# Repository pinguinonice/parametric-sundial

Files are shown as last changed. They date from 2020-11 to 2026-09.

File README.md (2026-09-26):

# parametric-sundial

A web generator for a 3D-printable **Bernhardt precision sundial** (equatorial ring dial with
a *Bernhardtsche Walze*, the shaped roller gnomon that builds the equation of time into the
shadow so the dial reads mean zone time to the minute). Enter a location, get four STL files:
the organic crescent dial, the two rollers (one per half year) and a stand tilted to your latitude.

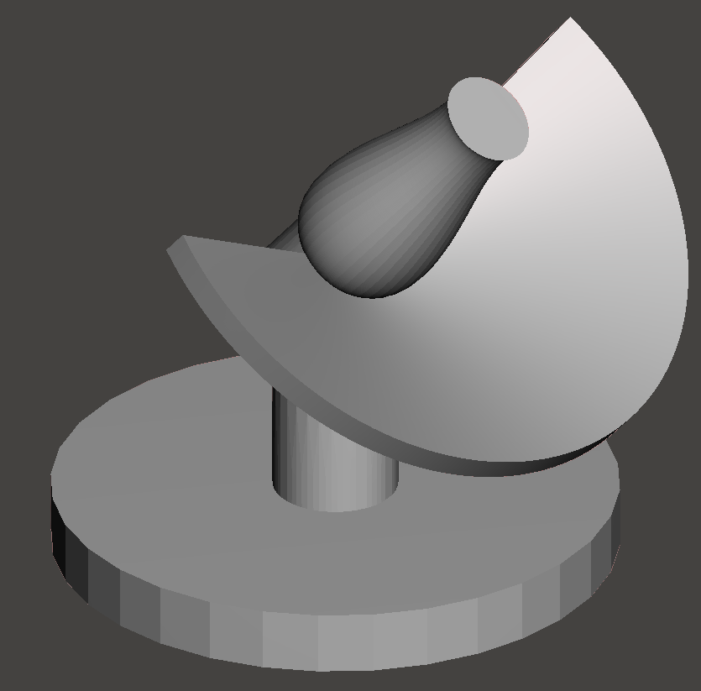
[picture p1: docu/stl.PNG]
original dial


## Run it

```bash
pip install -r app/requirements.txt
cd app && uvicorn sundialweb.api:app --reload
# open http://127.0.0.1:8000
```

or with Docker:

```bash
docker build -t sundial . && docker run -p 8000:8000 sundial
```

Command line, no server:

```bash
cd app && python -m sundialweb.cli --lat 48.7758 --lon 9.1829 --utc 1 --label "CET  UTC+1" -o out/
```

## Host it for free

The app is a single container (Dockerfile in the repo, honours `PORT`) and needs about 300 MB
of RAM and a few seconds of CPU per generation, so the free tiers are enough:

* **Hugging Face Spaces** (simplest, no card): create a Space with the *Docker* SDK, push this
  repo to it, and add `app_port: 8000` to the Space's README front matter. Spaces sleep after
  48 h without visitors and wake on the next request.
* **Render**: fork the repo, then *New > Blueprint* and pick `render.yaml`. The free web service
  sleeps after 15 min idle and takes about a minute to wake.
* **Google Cloud Run**: `gcloud run deploy --source .` from the repo root; scales to zero and the
  monthly free tier covers hobby traffic.

Generated results are cached in `SUNDIAL_CACHE` (default: the system temp dir); on these hosts
the cache is wiped on restart, which is fine.

## What the site does

The page is a four-beat flow, mobile first:

1. **Where am I.** The opening shows the last dial anyone made, with the sun looping through
   its day, beside a place card: use my location, search a town (or type coordinates), adjust
   on a map. The card shows the tilt, the engraved hour range and whether the zone keeps summer
   time before anything is built. One button: *Make my sundial*.
2. **Making it.** The facts of the dial appear at once (longest day, hours, roller waist, tilt),
   the analemma draws itself, and six named stages tick off as the server builds (design, dial,
   roller I, roller II, base, packing) with an estimate from the last builds. A repeat request
   comes from the cache. A closed tab can be reopened within ten minutes and picks the job up.
3. **Your dial today.** The viewer opens at the place's current standard time with the right
   roller fitted, or, when the sun is down or outside the engraved hours, at tomorrow's first
   light on the dial. The page's own shadows follow the sun of the moment shown.
4. **Take it home.** One ZIP button (size and bed hint), a *Buy us a coffee* button beside it
   that explains the server cost and never gates anything, part previews on a build plate with
   size, volume, weight and support hints, print notes, setup steps and a share link.

Settings (diameter, year, hour range, roller neck, labels, manual coordinates) and the full
numbers live one tap away in side sheets. A quiet *Dial map* in the top bar shows where dials
have been made (one entry per session per minute, coordinates to a tenth of a degree). Seven
languages, right-to-left included; the stories behind the design are in `docs/web-stories.md`.

### API

| Route | What it does |
|---|---|
| `GET /api/timezone?lat&lon` | standard offset, zone name, summer-time label |
| `GET /api/design?lat&lon&utc_offset_h&year&scale_radius…` | the dial's facts without meshing (a few seconds, cached) |
| `POST /api/generate` | `{cached: true, info}` at once, or `{job, estimates, stages}`; header `X-Sundial-Session` for the map |
| `GET /api/jobs/{id}` and `/events` | job status; server-sent events with the current stage |
| `GET /api/files/{key}/{name}` | `dial.stl`, `roller_1.stl`, `roller_2.stl`, `stand.stl`, `sundial.zip`, `viewer.glb` (decimated, for the browser) |
| `GET /api/latest` | the last dial made, for the opening picture |
| `GET /api/history` | where dials have been made, for the map |
| `GET /api/notes?lang` | print notes and setup steps from the site's strings (also used in the zip README) |

One worker thread builds dials in order. `SUNDIAL_MAX_QUEUE` (default 12) caps the queue,
`SUNDIAL_MAX_PER_CLIENT` (default 2) the pending dials per address. A fresh server builds a
Stuttgart dial at startup so the opening is never empty (`SUNDIAL_NO_WARMUP=1` disables it).
Every creation is logged to `creations.jsonl` in the cache dir with hashed session and client.

## How the geometry is computed (`app/sundialweb`)

* `solar.py`: NOAA/Meeus solar position (declination, equation of time, hour angle) and the
  *dial frame* (z = elevated celestial pole, y = shadow direction at true noon). Works in both
  hemispheres.
* `design.py`: for every 6 hours between the solstices the ray from the correct mean-time mark
  towards the sun is intersected with the polar axis: its distance gives the roller radius, its
  height the nodus position. The scale is rotated so the leading shadow edge is always ahead of
  the shadow centre (longitude offset + max equation of time + minimum neck radius). The roller
  is the envelope of all ray hyperboloids; near the solstices the hyperboloids overlap and no
  surface of revolution can be tangent to every ray, so the residual error is balanced between
  neighbouring days (about ±2.5 min for three weeks in December, ±1 min in June, otherwise
  below 0.5 min). The reading error of every day is reported.
* `meshing.py`: the crescent dial is a height field whose shape is derived from the sun rays
  themselves: under the winter hours it is a dish so the low winter sun lights the scale from
  above; where the low morning/evening sun has to pass the opposite wing the plate twists into a
  thin blade in the scale plane; where neither works the plate is cut away (the crescent's inner
  edge). Ticks and numerals are engraved with manifold booleans. Rollers are surfaces of revolution
  with an identification groove (I = one, II = two) and a threaded pin that screws into the hub
  (one rounded helical ridge, 2.5 mm pitch, 0.3 mm radial clearance, so it prints and fits without
  calibration; the collar seats on the hub and sets the height). The stand has a keyed pin so the
  dial can only sit in the right orientation. Its base is the place's own noon analemma (the
  sun's hour angle at twelve o'clock against its distance from the zenith), fattened into a flat
  plate with the months engraved along the curve. The figure is the shadow trace of a vertical
  gnomon and lies on the pole side of its foot, so the stem stands in the loop on the reader's side
  (the small June loop north of the tropics; in the south the December sun passes nearly overhead
  and the big loop wraps around the foot) and the other loop lies under the dial.
  The analemma is scaled so the foot fits its loop and, if needed, until the assembled dial can be
  tilted 22° in any direction before it tips. The API reports the achieved tip angle under
  `stability`.
* `api.py`: FastAPI, serves the frontend in `web/` and `/api/generate`, `/api/timezone`, `/api/sun`.

Tests (`app/tests`) cast real rays against the generated roller and dial meshes to verify that the
shadow edge lands on the right minute and that the dial body does not shadow its own scale.

## Printing

* `dial.stl` scale side up, tree supports under the wings and hub; 0.15–0.2 mm layers.
* `roller_1.stl`, `roller_2.stl` pin down, with supports under the bell.
* `stand.stl` plate down; the stem's bend needs no supports above about 25° latitude, tree supports under it otherwise.

Level the plate, point its long axis to true north (south on the southern hemisphere), drop the dial on
the keyed pin, screw in the roller for the current half year until its bell seats, and read at
the leading shadow edge. The dial is read from the pole side, where its face tilts towards you;
the numerals have their tops towards the hub and the hours run from right to left.

## References

* Wikipedia: [Bernhardtsche Walze](https://de.wikipedia.org/wiki/Bernhardtsche_Walze)
* G. Glaeser, W. Hofmann: *Über minutengenaue Sonnenuhren für die Mittlere Zeit*,
  Informationsblätter der Geometrie 2/2004.
* The original Python/Grasshopper experiments are kept in `sundial/`, `examples/` and `grasshopper/`.

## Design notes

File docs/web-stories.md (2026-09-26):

# Website stories

Status: everything below is built on the branch (S1.1 to S5.3, B1 to B12).
Open: nothing from this list; new ideas go into the backlog below first.

Plan for turning the page into a mobile-first flow with four beats:
**Where am I**, **Making it**, **Your dial today**, **Take it home**. Written as
user stories with acceptance criteria so each can be built, checked and shipped
on its own.

```
1 Where am I?  ->  2 Making it  ->  3 Your dial today  ->  4 Take it home
   locate/confirm     facts in 2 s     3D at now, or         ZIP, part previews,
   Generate           progress         first light tomorrow  donate
        \                                                        /
         `----------------- More (one tap away) ----------------'
                 settings, accuracy, setup, the story
```

One screen per beat on a phone. The 3D view is the constant; it enters at
beat 2 and stays pinned through beats 3 and 4. Everything explanatory lives
one tap away and never in the path.

## Ground rules

* **Mobile first.** Every story is accepted on a 390 px phone before desktop.
  Desktop is a two-column arrangement of the same components, never different ones.
* **One decision per screen.** The only required input is a place. Everything
  else has a good default and lives behind "More".
* **The 3D view is the reward.** The flow builds towards it and keeps it on
  screen once it exists.
* **Never gate.** The download is never behind a donation, an email or a wait.
  The donate ask is prominent and honest, and says so.
* **Seven languages, RTL included.** Every new string goes through `web/i18n.js`.
  Layout is checked in Arabic.

Effort: S under a day, M one to three days, L a week. "Must" = first release.

---

## Epic 1 · Where am I?

A visitor opens the page on a phone and, within ten seconds, has a place
confirmed and one big button to press.

### S1.1 Open on the question (Must, S)
As a visitor on a phone, I want the page to open on "where are you?" so that I
know what to do before I read anything.

* Above the fold on 390 × 844: one-line title, one sentence of promise, the
  location card, the primary button. No 3D canvas yet, no chapters.
* The story chapters (why the roller, Bernhardt, the analemma) move below the
  flow, reachable by scrolling or a "Why does this work?" link.
* Exactly one primary button: "Make my sundial" (i18n, all seven languages).

Today: the page opens on a hero with a 3D stage and long chapters before the
generator. Language selector and static demo mode stay.

### S1.2 Use my location (Must, S)
As a visitor, I want to tap "Use my location" and see my place named so that I
don't have to type anything.

* Geolocation is asked only after the tap, never on load.
* Within two seconds of a fix the card shows a place name (Nominatim reverse
  geocode), coordinates to two decimals with N/S/E/W, and the time zone in
  words: "CET, with summer time (CEST)" or "UTC+8, no summer time".
* Denied/failed geolocation falls back to the search field with a calm one-line
  message, no error styling.
* Map hidden by default on phones; "Adjust on map" expands it under the card.
  Visible beside the card on desktop.

Today: geolocation, search and timezone lookup exist in `app.js`; the map is
always rendered (Leaflet tiles on every visit).

### S1.3 Search a place (Must, S)
As a visitor, I want to type a town and pick it from a short list so that I can
make a dial for a place I am not standing in.

* Search field, Enter submits. Up to five results with country; a tap fills the card.
* "48.78, 9.18" or "48.78 N 9.18 E" is parsed without a lookup.
* Last confirmed place remembered on this device (localStorage in try/catch),
  offered next visit as "Stuttgart again?".

Today: search takes the first Nominatim hit silently.

### S1.4 A hint before the button (Must, S)
As a visitor, I want a hint of what I will get before I press the button so
that pressing it feels safe.

* The card shows two derived lines that update instantly with the place: the
  dial's tilt (= latitude) and the engraved hour range. Cheap call, no meshing.
* Outside the good latitude band the card says so before generating (below 27°
  "the winter sun will shade the dial", polar circle "hours 3 to 21"). Same
  words as the existing warnings, moved earlier.
* One quiet line: "150 mm dial · engraved for 2026 · change". "Change" opens More.

Needs: `GET /api/design?lat&lon&utc_offset_h&year` running `build_design` only
(hour range, sunrise/sunset extremes, tilt, roller profiles, noon analemma).
`build_design` is well under a second; only `build_all` is slow.

---

## Epic 2 · Making it

Generation takes on the order of a minute. The visitor should feel the dial
being shaped for their sky, not stare at a spinner, and never wonder whether
the page has hung.

### S2.1 Facts within two seconds (Must, M)
As a visitor who pressed the button, I want real facts about my dial within two
seconds so that the wait has already paid something back.

* The screen changes to the Making view: place name as heading, a fact list
  filling in line by line over two seconds: longest day (sunrise to sunset,
  clock time), engraved hours, minute ticks yes/no, roller waist from x to y mm,
  tilt, whether the dial gets a summer-time row.
* The analemma for this place draws itself (stroke animation ~2.5 s, respects
  reduced motion), month initials appearing as the line passes. Same figure
  that becomes the base plate.
* The two roller profiles fade in beside it with the solstice dates.

Needs: the fast design endpoint called first; the slow generate call starts in
parallel. `drawAnalemma` and `drawProfiles` exist in `viewer-core.js`.

### S2.2 Real progress (Must, L)
As a visitor, I want to see which part is being made right now and how far
along it is so that I trust the page is working.

* Progress line with five named stages in order: "Shaping the dial", "Cutting
  the numerals", "Turning roller I", "Turning roller II", "Casting the base".
  Each ticks when the backend reports it; a time-based estimate moves the bar
  in between so it never stands still for more than a second.
* Estimates from the median of the last ten builds on this server per stage,
  so it is honest on a slow free tier and a fast machine.
* Cached result: Making view is skipped after the facts have shown for one second.
* Closing the tab and returning within ten minutes resumes the same job (job id
  in sessionStorage).
* Failure shows the reason in plain words, keeps the facts on screen, offers
  "Try again" and "Try with a smaller dial".

Needs: generation becomes a job. `POST /api/generate` returns `{job, cached}`
at once; `GET /api/jobs/{job}` streams server-sent events (stage, done,
elapsed) and ends with the info payload. `build_all` gets a progress callback
between `build_dial`, engraving, each roller and `build_stand`. One worker
process with a queue is enough; queue position shown as a stage of its own
("Waiting behind 2 dials").

### S2.3 Something to look at (S)
As a visitor, I want something to read or look at while the parts are built so
that the minute feels short.

* Three short cards rotate every eight seconds: why the roller has a waist, why
  two rollers, why the base is the analemma. Three sentences each, chapter as
  "read more".
* Today's sun path for the place drawn as an arc with the current sun marked
  (same solar maths as the viewer).
* Nothing requires a tap; nothing auto-scrolls. When the meshes arrive the 3D
  view fades in over the top and the rest collapses.

---

## Epic 3 · Your dial today

The first 3D frame the visitor sees is their own dial, in their own sunlight,
at this moment. If the sun is down, it is tomorrow's first light.

### S3.1 Now (Must, M)
As a visitor, I want the dial shown at the current time in my place so that I
can compare the shadow with my phone's clock right now.

* Viewer opens at the place's current zone time (device clock + place's UTC
  offset, summer time applied when the zone has it and the date is inside it).
  Readout: "Now, 14:37 · 26 September".
* Correct roller for the date fitted and named; shadow edge on the minute.
  Readout shows "sun 5.6 min ahead of the clock".
* Camera starts on the pole side, slightly above (reading position); the sun
  sweeps in from sunrise to now over 2.6 s as today.
* Time scrubbable with the slider; "Now" chip snaps back.

Today: viewer opens at 12:00 on 20 May of the design year. Sweep, roller choice
and readout exist. Browser-side summer-time bookkeeping needs the zone name
(already returned as `tz` by `/api/timezone`).

### S3.2 Tomorrow if no sun (Must, S)
As a visitor at night, I want to see the dial at tomorrow's first useful light
so that I still get a real reading, not a dark scene.

* If the sun is below the horizon now, or the hour is outside the engraved
  range, the viewer opens at the first engraved hour after the next sunrise:
  "Tomorrow, 7:00 · first light on the dial".
* Polar night: search continues day by day and the readout names the date.
* Chip row becomes "Now · Tomorrow morning · Noon · 21 June · 21 December".

Today: `sunriseMinutes` exists; below-horizon and outside-hours states are
detected in `setTime`.

### S3.3 One accuracy line (S)
As a visitor, I want a single line under the 3D view telling me how accurate
this dial will be so that I know what I am printing.

* "Reads the clock to the minute all year" or "Within 2 minutes from 3 to 15
  March", from the existing accuracy report.
* Shadowed days as a second sentence. API warnings appear here in the same
  tone, not as a red list.
* "Details" opens the full facts (Epic 5).

### S3.4 Touch (M)
As a visitor on a phone, I want to move around the dial with one finger and not
fight the page scroll.

* Canvas full width, 4:5 on portrait phones, 16:9 on desktop. One finger
  orbits, two fingers zoom, page scrolls only when the drag starts outside.
* Pixel ratio capped at 2; render loop pauses when off screen.
* "Apart" (exploded view) becomes a toggle chip in the canvas corner.

---

## Epic 4 · Take it home

Downloading is one tap. Everything a maker might want to know before printing
is one more tap, and the thank-you ask stands beside the download without ever
standing in front of it.

### S4.1 One button (Must, S)
As a visitor who likes what I see, I want one obvious button that gives me
everything so that I don't have to understand the parts first.

* Directly under the 3D view, full-width primary button "Download the sundial
  (ZIP, 4 parts)" with the size in MB. Appears the moment the meshes load, same
  screen as the viewer.
* ZIP keeps README.txt and gets a real name from place slug and size, e.g.
  `sundial-stuttgart-150mm.zip`.
* Muted line under it: "STL files for any printer · sized for a 220 mm bed",
  bed figure computed from the largest part.

### S4.2 Preview the parts (Must, M)
As a maker, I want to see each part alone, lying as it should on the print
bed, so that I know the orientation before I open a slicer.

* "Preview the parts" expands four tiles: Dial, Roller I, Roller II, Base. Each
  is a small live 3D render of that part alone on a grey build plate with a
  10 mm grid, in print orientation: dial scale side up, rollers pin down, base
  plate down.
* Each tile: size in mm (x × y × z on the bed), volume in cm³, estimated weight
  at PLA density 1.24 g/cm³ ("solid, before infill").
* Support hints from the README: "tree supports under the wings and hub",
  "supports under the bell", "no supports above 25° latitude".
* Each tile has its own "Download dial.stl" link. Tapping a tile enlarges it
  to the full stage with orbit.

Needs: per-part bounds already in `info.bounds`; volume is one trimesh call per
part and joins the info payload. Print orientation is a fixed rotation per
part; bed hint rounds the largest footprint up to 180/220/250/300 mm.

### S4.3 Donate beside download, no dark patterns (Must, S)
As the maker of this site, I want a clear, prominent donate button beside the
download so that people who value the work can say thanks, without anyone
feeling pushed.

* Download and donate side by side on desktop, stacked on phones. Download
  first and primary (brass fill); donate second and clearly secondary
  (outlined, same height and radius, not smaller, not greyed out).
* Donate reads "€1 for the maker" with a PayPal mark and one line: "Optional.
  The files are yours either way." Links to paypal.me/pinguinonice/1EUR in a
  new tab.
* No interstitial, no countdown, no pre-ticked box, no reminder after the
  download, no "are you sure". The download starts on the first tap every time.
* After a download tap the donate line gains a small "Thank you for printing
  one" and nothing else changes.

### S4.4 Notes one tap away (S)
As a maker, I want the print and setup notes one tap from the download so that
I do not need to find the README later.

* "Print notes" and "Setting it up" as two collapsed sections under the
  download row. Print notes: layer height, supports per part, thread needs no
  calibration, screw the roller in until the collar seats. Setting up: the
  four existing steps (level, aim at true north, seat the dial, choose the
  roller) with the pole-side wording.
* Same text as README.txt from one source of truth (i18n strings rendered
  server-side or shared JSON), so the two never drift.
* "Share this dial" copies a link encoding place, size and year; reopening
  lands on Making with those values (cache hit makes it instant).

---

## Epic 5 · More, one tap away

Nothing in Epics 1 to 4 asks the visitor for a number. The people who want
numbers get all of them here.

### S5.1 Settings sheet (Must, S)
As a tinkerer, I want to change dial size, hour range, year and roller waist
so that the dial fits my printer and my taste.

* Bottom sheet on phones, side panel on desktop, opened from "change" on the
  location card or "Adjust" next to the download. Fields: diameter (slider
  80 to 300 mm with the bed hint live), year, hours automatic or first/last,
  minimum roller radius, zone label and summer label as text, manual UTC offset.
* Any change shows "Regenerate" as the primary action and returns to Making;
  the previous result stays downloadable until the new one arrives.
* Defaults restorable with one tap.

### S5.2 Full details (S)
As a curious visitor, I want the full facts of my dial so that I can check it
against what I know.

* "Details" under the 3D view opens the full facts list: place, hours, longest
  day, roller radii, tilt and plate size, dial footprint, accuracy by date
  range, shadowed days, tip-over angle from the stability report, thread pitch
  and clearance.
* The analemma and roller-profile figures live here with their captions.

### S5.3 Keep the story (S)
As a reader, I want the story of the roller sundial to still be on the site so
that the page keeps its character.

* The existing chapters become a "Why this works" section below the flow,
  text unchanged; footer sources stay.
* `web/build_demo.py` renders the Stuttgart result into the same four-beat
  layout starting at beat 3, so the hosted preview and the live site match.

---

## Backlog after the first prototype

Ideas from Philipp, to be worked in gradually with a commit per step:

* **B1 · Latest dial as the opening picture.** *Done in the prototype:*
  `/api/latest` returns the last dial anyone made; the opening shows it in
  3D with the sun looping through its day and "made 4 min ago". A fresh
  server makes a Stuttgart dial at startup so there is always one.
* **B2 · Rate limit and queue cap.** *Done in the prototype:* at most 12
  dials waiting, at most 2 pending per address (`SUNDIAL_MAX_QUEUE`,
  `SUNDIAL_MAX_PER_CLIENT`), a 429 with a plain sentence otherwise.
* **B3 · User first.** Every screen must feel like an exciting intro, not a
  form. Keep asking on each screenshot: what is the one thing here, and is
  anything on the screen not helping it?
* **B4 · Graphical, from the real model.** No pre-rendered pictures or
  videos anywhere. Everything that moves is drawn live from the visitor's
  own dial, or from the latest one made: the sun sweep, the analemma, the
  roller profiles, the parts on the bed.
* **B5 · Judge the screenshots.** After every change, look at phone and
  desktop screenshots of each beat and fix what looks wrong before moving
  to the next story. Mobile first, desktop kept in mind.

* **B6 · Shadows follow the sun.** *Done:* the page's card and button
  shadows take direction and length from the sun of the moment shown in
  the viewer (long at low sun, soft and centred at night).
* **B7 · Dial map.** *Done:* a quiet "Dial map" link in the top bar opens
  a map of where dials have been made, one entry per session per minute,
  coordinates rounded to a tenth of a degree, no identities. Every
  creation is logged internally to `creations.jsonl` in the cache dir.
* **B8 · Coffee, not donate.** *Done:* the button reads "Buy us a coffee ·
  and help keep this site online"; a tap opens a short note on the server
  cost before the PayPal link. Nothing is gated.
* **B9 · Render contrast.** *Done:* the floor is a darker stone so the
  light dial reads against it; keep checking every render for elegant but
  clear contrast.
* **B10 · Working style.** Ideas arrive while building; they are noted
  here and folded into the plan, the current increment is finished and
  committed first, then the next one is picked from this list.

* **B11 · Fast, with calm placeholders.** *Done:* the viewer loads one
  decimated GLB (about 1 MB gzipped) instead of 28 MB of STL; files carry
  immutable cache headers and gzip; three.js modules are preloaded and the
  CDNs preconnected; Leaflet and the Arabic fonts load only when a map or
  Arabic is opened; the stage shows a soft breathing sun dot until the
  meshes arrive. Nothing else spins or flashes.

* **B12 · Housekeeping that showed up while judging screenshots.** *Done:*
  the import map precedes the module preloads (a reload broke without it),
  first light means the sun five degrees up so the frame is lit, a vertical
  swipe on the viewer still scrolls the page, the hour hint uses the
  generator's own clamp, the dial cache is pruned by size, user-supplied
  text is escaped, and a fresh server's opening dial is retried while the
  warm-up build runs.

## Order of work

Three slices. Each leaves the site working and shippable.

| Slice | Stories | What the visitor gets |
|---|---|---|
| 1 · Flow | S1.1 S1.2 S1.3 S1.4 S4.1 S4.3 S5.1 S5.3 | Mobile-first four-beat layout with today's synchronous generation, the download row and donate beside it. Frontend plus the fast design endpoint. |
| 2 · Making | S2.1 S2.2 S2.3 S3.1 S3.2 S3.3 | Real progress from a job endpoint, facts and analemma during the wait, the viewer opening at now or tomorrow's first light. |
| 3 · Parts | S4.2 S4.4 S3.4 S5.2 | Part previews on a build plate with weights and support hints, print notes from one source, share links, better touch handling. |

## Open questions

* **Server.** The free Render tier sleeps, so the first visitor of the day
  waits for a cold start before the job begins. Show it as a stage ("Waking
  the workshop") or pay for an always-on instance?
* **Weight.** Quote solid weight at PLA density, or a slicer-style estimate at
  15 % infill? Solid is honest and simple; infill is closer to the slicer.
* **Donate amount.** Keep the fixed €1 link, or 1 / 3 / 5 as three plain
  buttons, none preselected?
* **Share links.** Place slug plus size in the URL hash is enough for a cache
  hit. Fine to expose coordinates to two decimals in a share link?

Everything above builds on code already on the branch: the geometry, the
timezone lookup, the viewer, the seven-language strings and the cache keyed by
request. The only new backend pieces are the fast design endpoint and the job
with progress events.

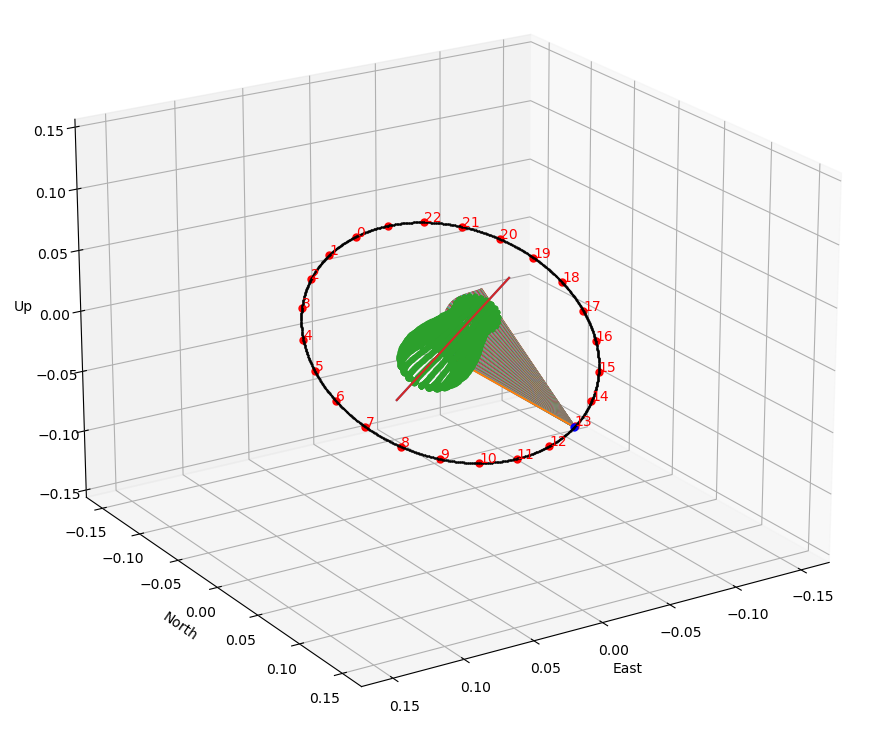
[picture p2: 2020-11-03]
docu/stuttgart_fall.PNG

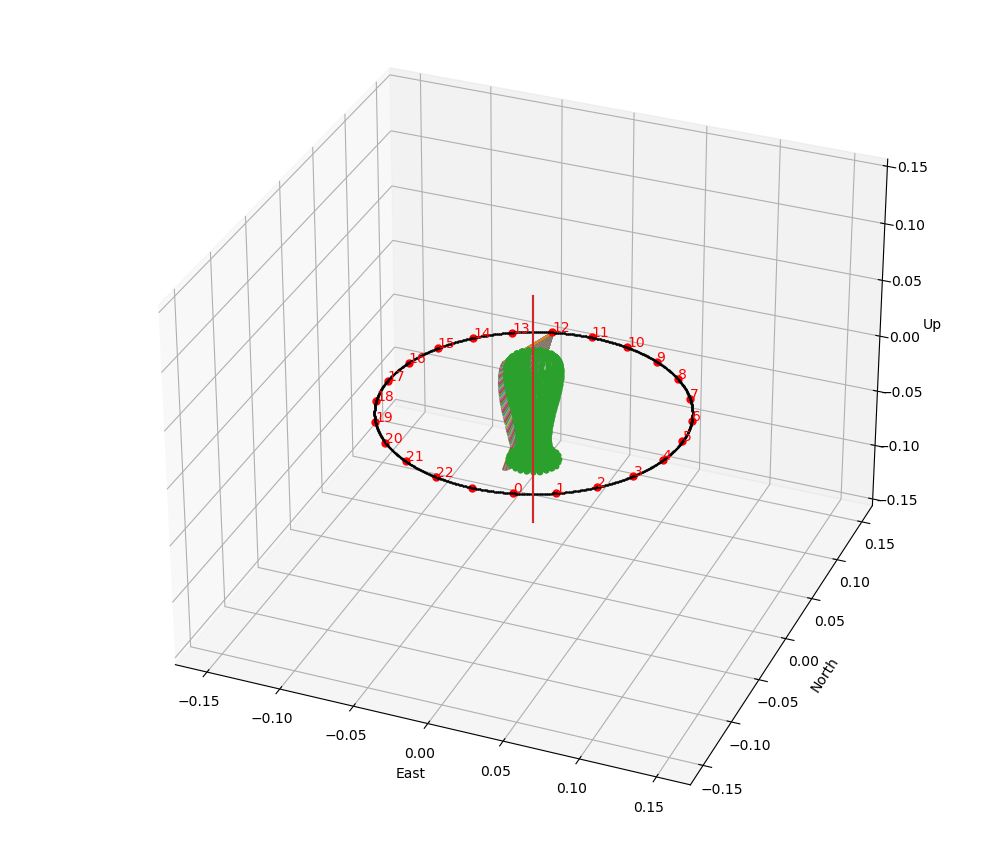
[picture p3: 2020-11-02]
docu/pol.PNG

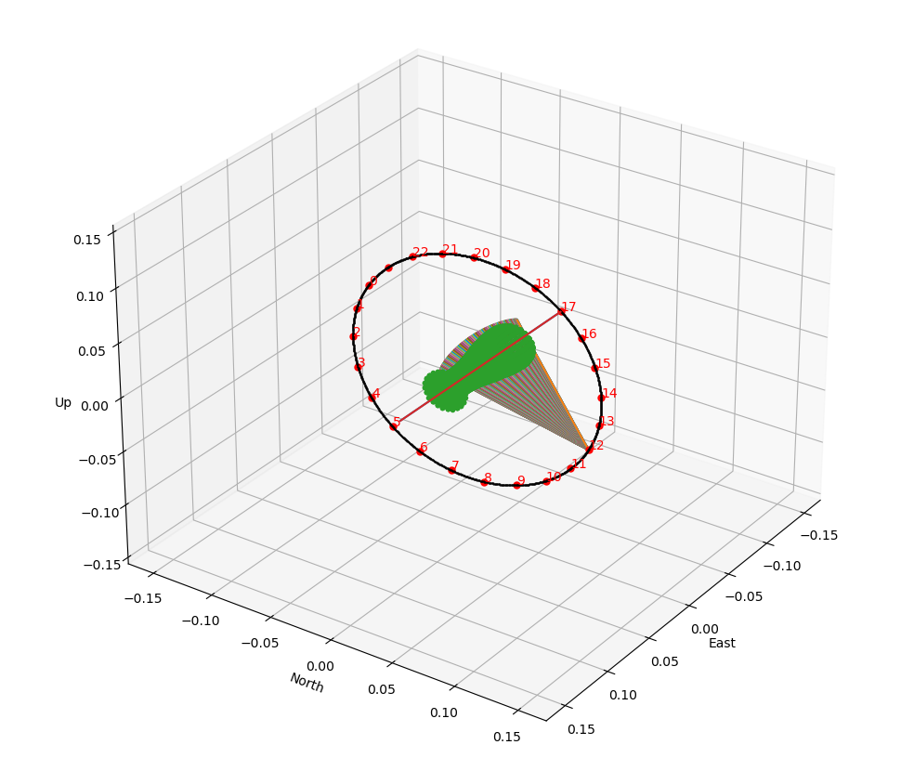
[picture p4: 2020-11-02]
docu/stuttgart.PNG

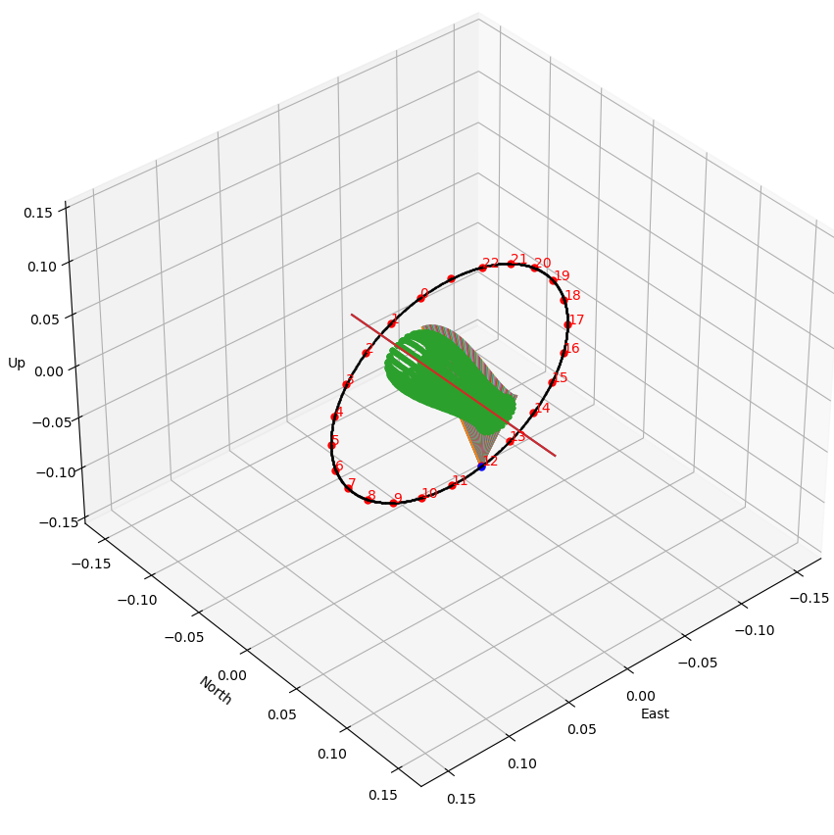
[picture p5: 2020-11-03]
docu/equator.PNG

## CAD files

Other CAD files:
grasshopper/sundialGrasshopper.3dm

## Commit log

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2020-11-03 some rhino grasshopper experiments
    [P.csv, P0.csv, P1.csv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]
2026-09-25 Add web generator for a 3D-printable Bernhardt roller sundial
    Location in, four STLs out: crescent dial, two half-year rollers and a
    latitude-tilted stand, with a Three.js preview that simulates the real
    sun and shadow for any date and time.
    Geometry (app/sundialweb):
    - solar: NOAA/Meeus sun position, dial frame for both hemispheres
    - design: ring offset from longitude, equation of time and minimum neck;
    hour range from earliest sunrise/latest sunset; roller profile as the
    envelope of the ray hyperboloids with the residual solstice error
    balanced between neighbouring days and reported per date
    - meshing: dial height field derived from the winter rays (dish under the
    winter hours, th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
2026-09-25 Redesign the site as a story-led page with a shared 3D viewer
    Hero preview with real sun and shadow, chapters on the equation of time,
    Bernhardt's roller and the ray-derived shape, live analemma and roller
    profile figures, then the generator, setup steps and the honest limits.
    Viewer core shared with the hosted preview: lit materials, environment,
    recomputed normals, readout as a caption below the canvas.
    Claude-Session: https://claude.ai/code/session_011Ak89JkxWu75J3gvYdMznG
2026-09-25 Make the dial surface continuous and prove it
    The dish-to-blade twist is now a two-dimensional field with a bounded
    rate of change (full fold over 8 degrees / 6 mm), the base surfaces are
    slope-bounded lower envelopes, and the crescent's inner edge may only
    sweep, never notch. A continuity report (watertight, single component,
    max height step between neighbouring samples) is exposed in the API and
    asserted in the tests. Cost: the far wing shadows the first and last
    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
2026-09-25 Build the blade and dish deepening as smooth surfaces
    The blade is a cone per column fitted under that column's own rays, the
    dish deepening a smooth per-column factor, both smoothed along the ring;
    the fold gets a soft blur after its slope bound. The continuity report
    now includes a curvature metric (max second difference of the height
    field). Rasterisation texture no longer reaches the printed part.
    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
2026-09-25 Engrave text glyph by glyph along the ring; smoother inner edge; audit camera
    Each character gets its own surface frame so lines follow the dished
    plate instead of a flat chord that missed the surface at its ends. The
    crescent's inner edge is a smoothed upper envelope of the cut. The viewer
    gains a scripted camera for the visual audit and a warm ground bounce so
    undersides are legible.
    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
2026-09-25 Organic forms: rounded plate edges, blended hub, pebble base with curved stem
    The plate section is a closed loop with true half-rounds on the rim and
    inner edge, thickness measured along the surface normal, and the dish
    settling onto the hub with a soft boss underneath. The hub is a revolved
    form with a flared neck and rounded foot. The stand is a flat-bottomed
    pebble with a stem that rises vertically and bends into the polar axis,
    tapering like the roller; the location is engraved on the pebble.
    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
2026-09-25 Organic details: leaf-shaped horn tips, filleted hub, seamless stem foot, dome-following base lettering
    - Inner edge of the crescent now sweeps out to the rim along a superellipse
    so the horns end in rounded points; ray cuts are smoothed over 16 degrees
    - Edge rounds are built perpendicular to the inner-edge curve and sections
    are sampled densely towards the hub, removing terraces on the underside
    - Hub top edge is a 3.5 mm round; the underside boss around the hub is
    softer (5 mm over 14 mm)
    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
2026-09-25 Stand sized for stability; roller screws into the hub on a printable thread
    Stability
    - The pebble base is sized from the centre of mass of the assembled dial
    (dial, heavier roller, stem, pebble): it grows into an egg towards the
    overhang until the whole assembly can be tilted 22 degrees in any
    direction before it tips. The achieved tip angle and footprint margin
    are reported as 'stability' in the API and in the zip README.
    - Pebble, foot round and stem are one continuous surface (no boolean), so
    the tangential junctions carry no sliver triangles; lettering is scaled
    to fit the pebble's width.
    - test_stand_does_not_tip checks four latitudes on both hemispheres
    against the centr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
2026-09-25 Smoother fold on high-latitude dials
    - The twist may only grow from the noon centre towards either tip, so the
    fold between dish and blade is a single sweep instead of a ripple
    - Within the scale band (never cut) an isolated ray constraint is relaxed
    to what its neighbours within 2 degrees allow, and narrow dips of the
    fold are closed over 3 degrees; the few days this shadows are listed in
    the report as before
    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
2026-09-26 Base plate is the place's noon analemma; dial lifted instead of cantilevered
    - The stand's base is the noon analemma (the sun's hour angle at twelve
    o'clock against its distance from the zenith), fattened into a flat
    5 mm plate with the curve, month ticks and initials, location and zone
    engraved on top. The stem stands inside the loop on the reader's side:
    the small loop of the eight north of the tropics, the large one in the
    south. Flat underside, quarter-round edge falling from the top.
    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
2026-09-26 Stem stands in the smaller loop of the analemma on both hemispheres
    South of the equator the loop nearest the reader is the big December
    loop; the stem now always takes the smaller loop, the big one carries
    the rest of the plate. Southern stands still tip only beyond 32 degrees.
    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
2026-09-26 Continuous roller-to-hub joint, summer-time numeral row, plate orientation by hemisphere
    - Roller foot is one continuous flare (smoothstep) from the seat inside
    the hub up into the computed profile; the identification grooves are
    shallow rounded coves on the flare. The hub top rises around the seat in
    a 2 mm concave fillet, so hub and roller read as one form. The analytic
    sun-blocking model includes the cup.
    - Where the place keeps summer time (from the tz database), a second,
    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
2026-09-26 Bell-shaped roller foot onto the hub shoulder; dial read from the pole side
    - The roller's foot is a bell (cubic Hermite) that widens down onto the
    hub and meets the hub top horizontally at the radius where the hub's
    3.5 mm shoulder round begins, tangent to the computed profile above:
    roller and hub form one ogee across the seam. Identification grooves
    are rounded coves on the bell. The hub top is flat inside the shoulder.
    - All lettering is turned for the reader standing on the pole side, where
    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
2026-09-26 Add mobile-first website user stories
    Four-beat flow (locate, making with progress, dial at now or tomorrow's
    first light, download with part previews and donate), split into five
    epics with acceptance criteria, three delivery slices and open questions.
    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
2026-09-26 API: fast design facts, build jobs with progress events, part print facts
    GET /api/design returns hour range, longest day, roller radii and accuracy
    without meshing. POST /api/generate now returns a cached result at once or
    a job id; one worker thread builds in order and GET /api/jobs/{id}/events
    streams the stage (design, dial, roller I, roller II, base, export) with
    per-stage estimates from the last builds. The info gains per-part size,
    volume and PLA weight, a bed-size hint, a zip name from the place, and the
    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
2026-09-26 Sun-driven page shadows, dial map with creation log, coffee note, darker floor
    Card and button shadows take direction and length from the sun of the
    moment in the viewer. A quiet 'Dial map' link opens a map of where dials
    have been made: one entry per session per minute, coordinates to a tenth
    of a degree, no identities; every creation is logged to creations.jsonl.
    The support button reads 'Buy us a coffee' and opens a short note on the
    server cost before the PayPal link. The render floor is a darker stone so
    the light dial has contrast. Ideas noted in the stories backlog.
    Claude-Session: https://claude.ai/code/session_011Ak89JkxWu75J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
2026-09-26 Settings and details as side panels on desktop; README notes from the site strings
    /api/notes serves the print notes and setup steps parsed from web/i18n.js,
    and the zip README uses the same English text, so the two cannot drift.
    The size note in the settings sheet shows its diameter again. The render
    floor is a darker taupe so the light dial reads in full daylight.
    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
2026-09-26 Import map before module preloads (fixes reload), first light at 5 degrees of sun
    A reload resolved 'three' before the import map was parsed because the
    module preloads came first; the map now precedes them. The unused fetch
    preload is gone. 'First light on the dial' now means the sun at least
    five degrees up, so the opening frame is lit rather than dusk.
    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
